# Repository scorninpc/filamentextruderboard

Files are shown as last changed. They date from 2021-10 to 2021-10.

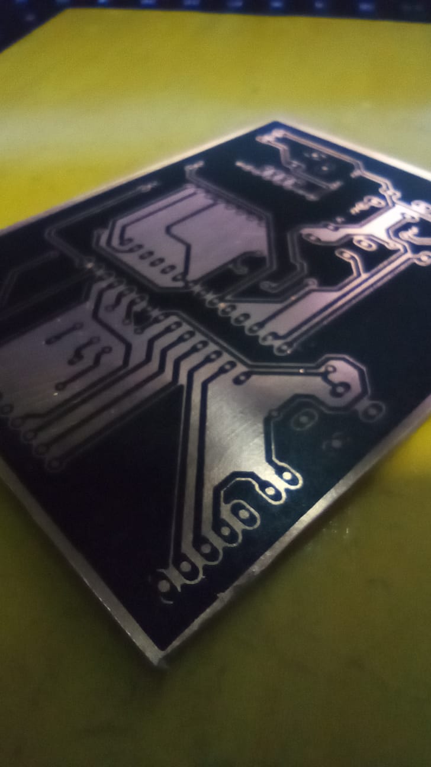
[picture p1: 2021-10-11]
board/photos/03.jpeg

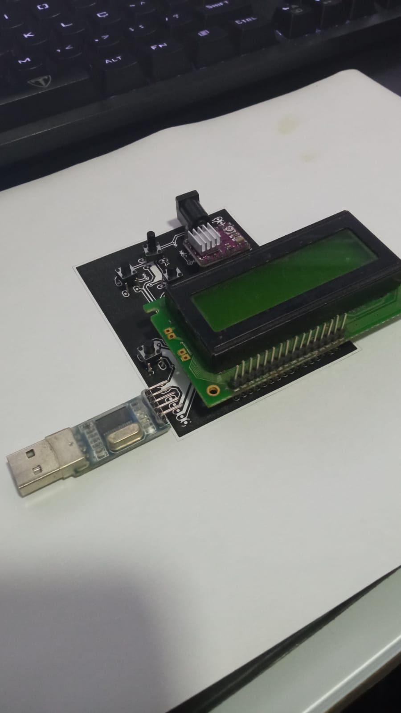
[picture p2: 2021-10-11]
board/photos/02.jpeg

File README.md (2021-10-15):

# Filament Extruder Board

Board to control heater and step motor for PET filament extruder

## Media

https://imgur.com/a/M2m6THj

## Tips

- Use MOSFET module to connect hotend. If you use 25A MOSFET module, this work only with 12v, so wire here (https://imgur.com/slLvls0) to use 5v of arduino

## How to use

- ENTER button to change what configure. Indicated by arrow
- UP and DOWN configure the value of indicated device
- LONG PRESS ENTER to start or stop the device indicated by arrow

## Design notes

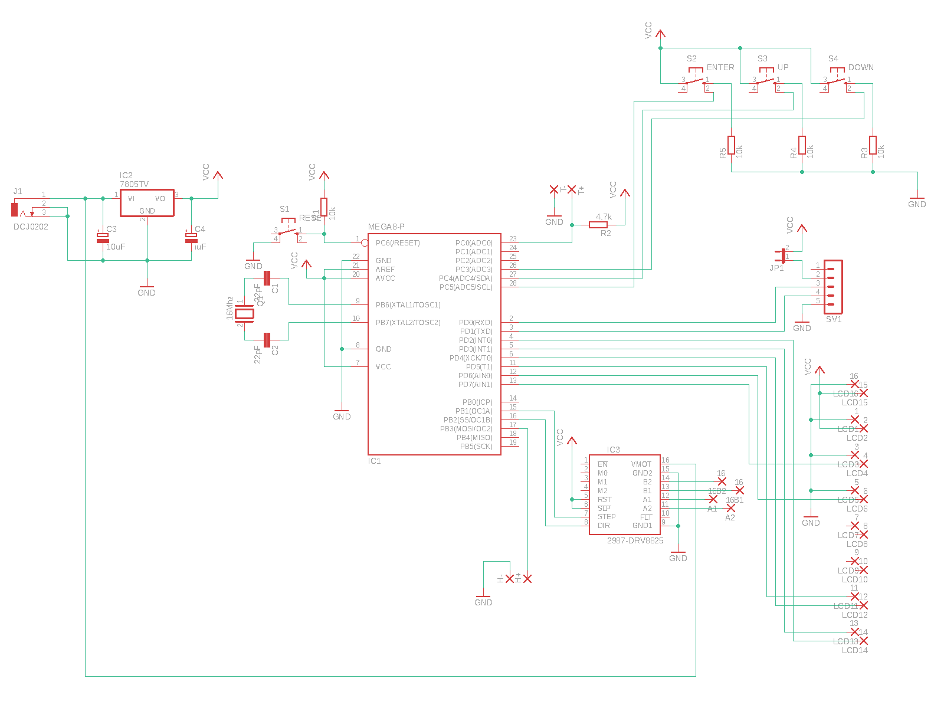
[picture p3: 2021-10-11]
board/schematic.png

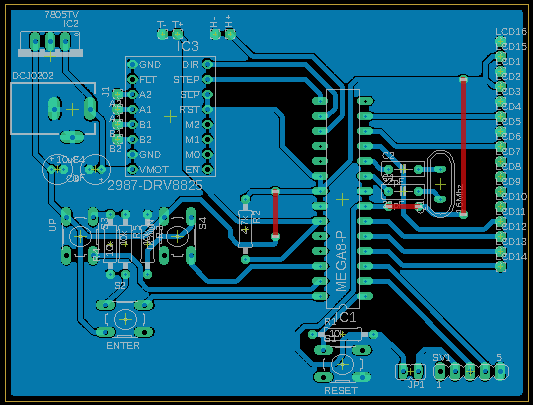
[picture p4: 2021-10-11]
board/board.png

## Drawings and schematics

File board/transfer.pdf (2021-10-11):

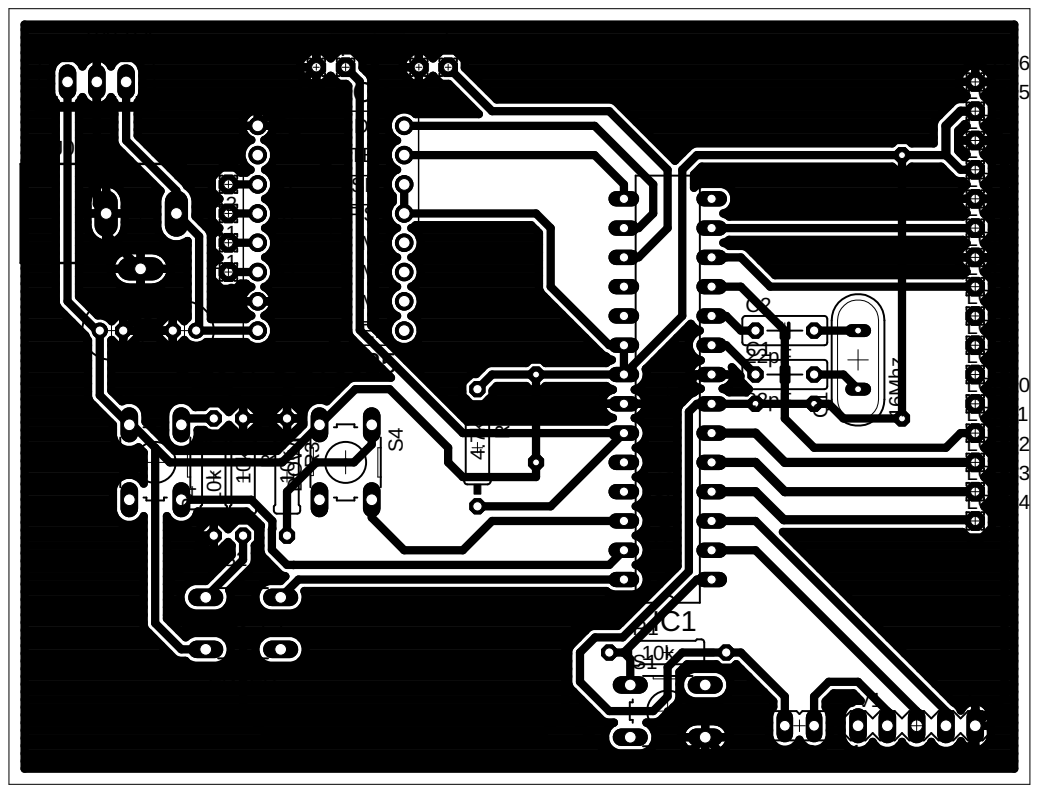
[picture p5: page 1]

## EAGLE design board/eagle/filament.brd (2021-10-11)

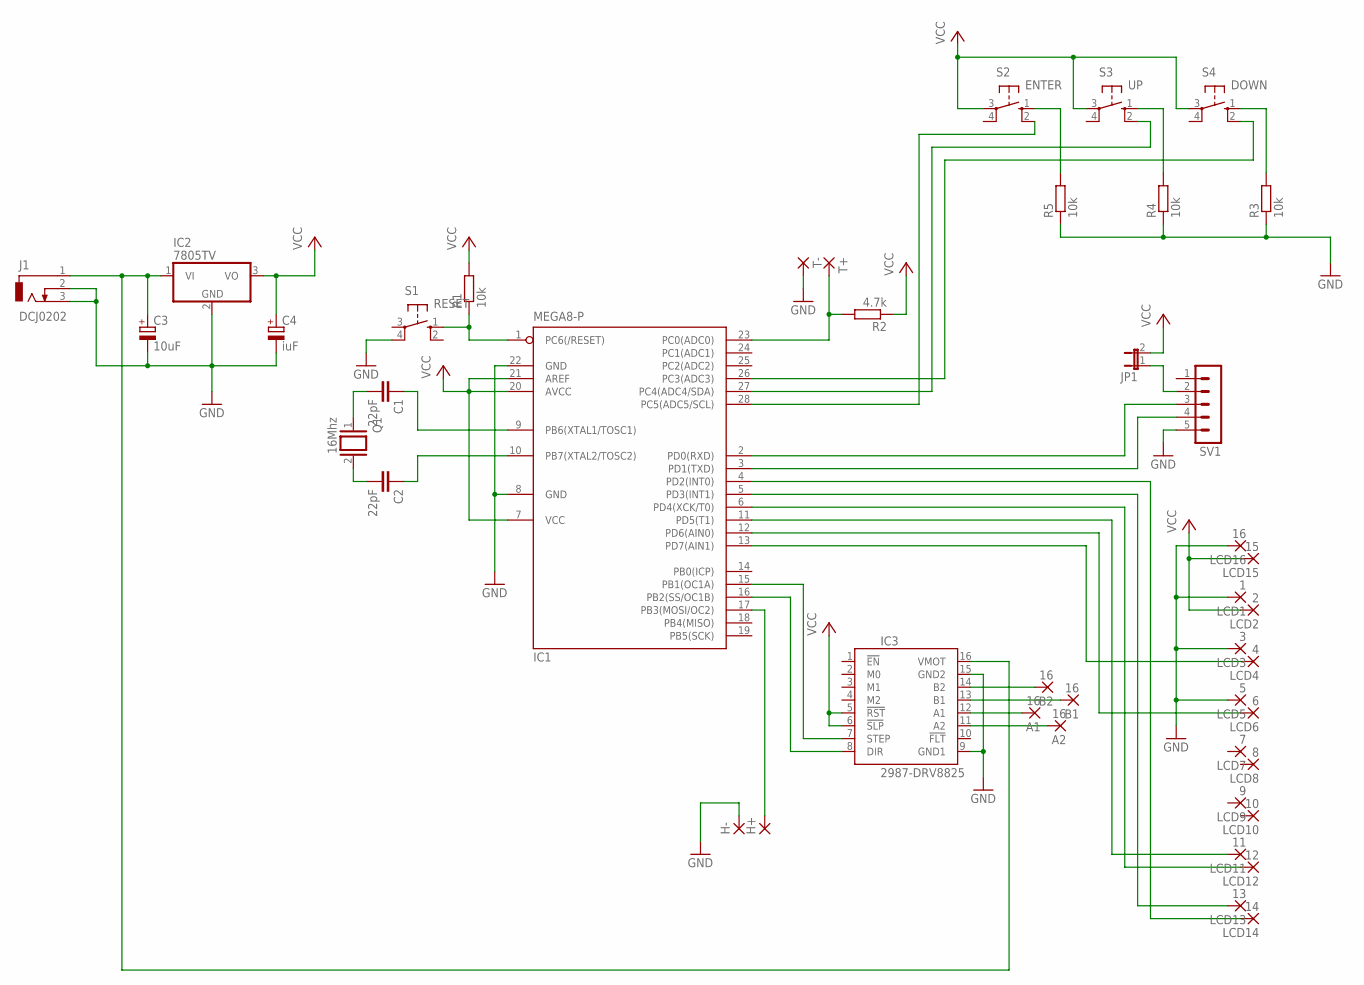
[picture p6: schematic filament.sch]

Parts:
A1, A2: 16; 1,6/0,8
B1, B2: 16; 1,6/0,8
C1, C2: 22pF; C050-025X075
C3: 10uF; E2-5
C4: iuF; E2-5
H+: 1,6/0,8
H-: 1,6/0,8
IC1: MEGA8-P; DIL28-3
IC2: 7805TV; TO220V
IC3: 2987-DRV8825; DRV8825
J1: DCJ0202
JP1: JP1E; JP1
LCD1: 1; 1,6/0,8
LCD2: 2; 1,6/0,8
LCD3: 3; 1,6/0,8
LCD4: 4; 1,6/0,8
LCD5: 5; 1,6/0,8
LCD6: 6; 1,6/0,8
LCD7: 7; 1,6/0,8
LCD8: 8; 1,6/0,8
LCD9: 9; 1,6/0,8
LCD10: 10; 1,6/0,8
LCD11: 11; 1,6/0,8
LCD12: 12; 1,6/0,8
LCD13: 13; 1,6/0,8
LCD14: 14; 1,6/0,8
LCD15: 15; 1,6/0,8
LCD16: 16; 1,6/0,8
Q1: 16Mhz; QS
R1, R3, R4, R5: 10k; 0207/10
R2: 4.7k; 0207/10
S1: RESET; B3F-10XX
S2: ENTER; B3F-10XX
S3: UP; B3F-10XX
S4: DOWN; B3F-10XX
SV1: MA05-1
T+: 1,6/0,8
T-: 1,6/0,8

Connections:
GND: C3.-, C4.-, H-.1, IC1.8 (GND), IC1.22 (GND), IC2.2 (GND), IC3.9 (GND1), IC3.15 (GND2), J1.2, J1.3, LCD1.1, LCD3.1, LCD5.1, LCD16.1, R3.1, R4.1, R5.1, S1.4 (P1), SV1.5, T-.1
unnamed: C1.2, Q1.1
unnamed: C2.2, Q1.2
unnamed: C2.1, IC1.10 (PB7(XTAL2/TOSC2))
unnamed: C1.1, IC1.9 (PB6(XTAL1/TOSC1))
unnamed: IC1.1 (PC6(/RESET)), R1.1, S1.1 (S)
unnamed: B2.1, IC3.14 (B2)
unnamed: IC1.3 (PD1(TXD)), SV1.4
unnamed: IC1.2 (PD0(RXD)), SV1.3
unnamed: JP1.1, SV1.2
unnamed: IC1.4 (PD2(INT0)), LCD14.1
unnamed: IC1.5 (PD3(INT1)), LCD13.1
unnamed: IC1.6 (PD4(XCK/T0)), LCD12.1
unnamed: IC1.11 (PD5(T1)), LCD11.1
unnamed: IC1.23 (PC0(ADC0)), R2.2, T+.1
unnamed: IC1.13 (PD7(AIN1)), LCD4.1
unnamed: H+.1, IC1.17 (PB3(MOSI/OC2))
unnamed: IC1.12 (PD6(AIN0)), LCD6.1
unnamed: R5.2, S2.1 (S)
unnamed: R4.2, S3.1 (S)
unnamed: R3.2, S4.1 (S)
unnamed: IC1.28 (PC5(ADC5/SCL)), S2.2 (S1)
unnamed: IC1.27 (PC4(ADC4/SDA)), S3.2 (S1)
unnamed: IC1.26 (PC3(ADC3)), S4.2 (S1)
unnamed: IC1.15 (PB1(OC1A)), IC3.7 (STEP)
unnamed: IC1.16 (PB2(SS/OC1B)), IC3.8 (DIR)
unnamed: B1.1, IC3.13 (B1)
unnamed: C3.+, IC2.1 (VI), IC3.16 (VMOT), J1.1
unnamed: A1.1, IC3.12 (A1)
unnamed: A2.1, IC3.11 (A2)
VCC: C4.+, IC1.7 (VCC), IC1.20 (AVCC), IC1.21 (AREF), IC2.3 (VO), IC3.5 (!RST), IC3.6 (!SLP), JP1.2, LCD2.1, LCD15.1, R1.2, R2.1, S2.3, S3.3, S4.3

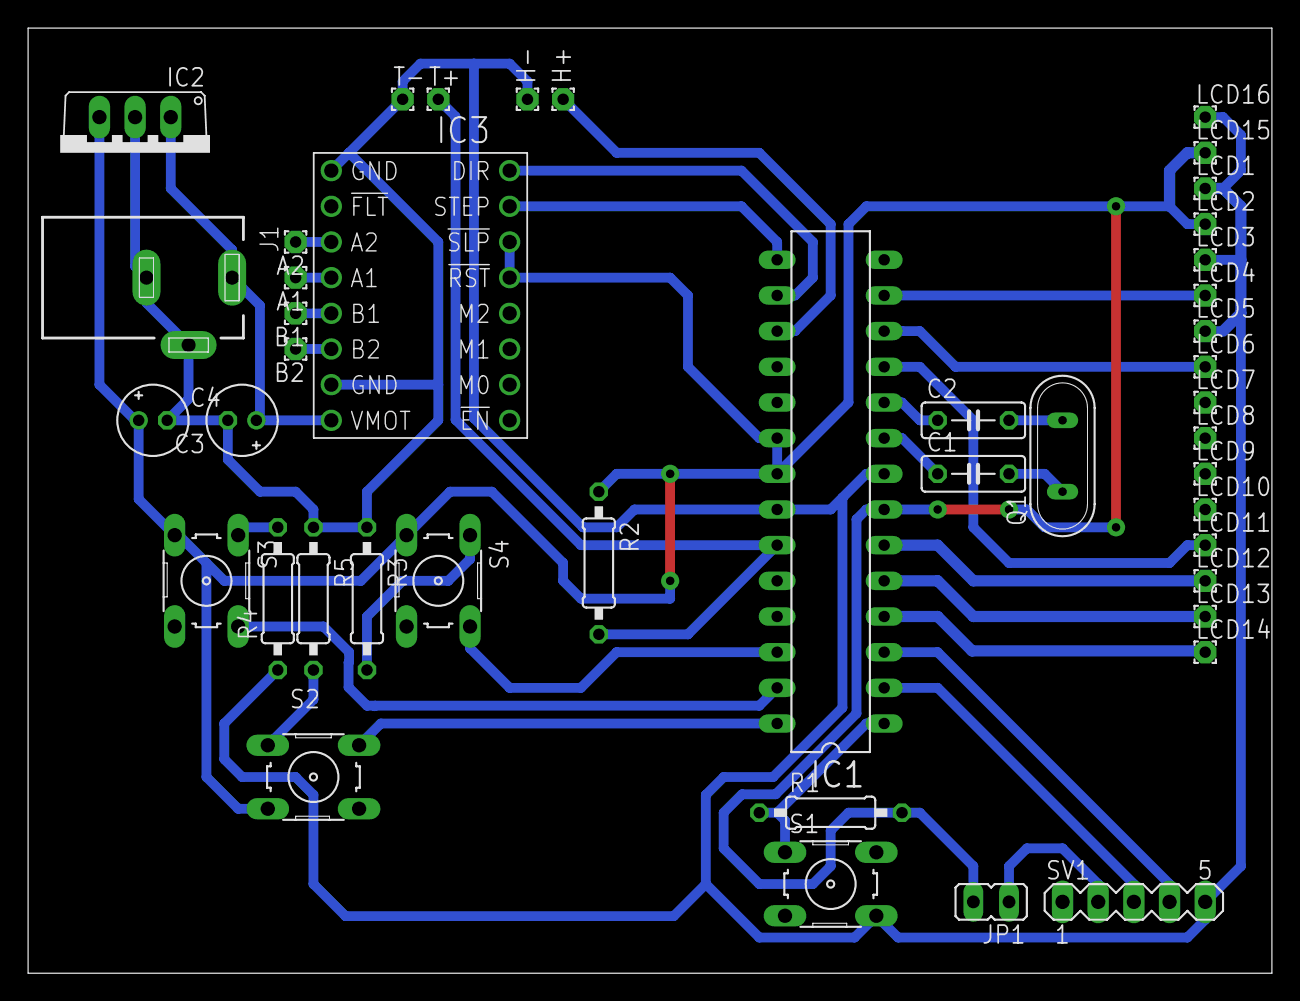
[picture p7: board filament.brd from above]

Board: 2 copper layers, 88.6 x 67.3 mm, 44 parts (0 on the bottom side), 31 nets.

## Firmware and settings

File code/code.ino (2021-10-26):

/**
 * arduino-cli compile --fqbn arduino:avr:uno code
 * arduino-cli upload -p /dev/ttyUSB0  --fqbn arduino:avr:uno code
 */

#include <LiquidCrystal.h>
#include <PID.h>
#include <EEPROM.h>
#include "Button.h"
#include <AccelStepper.h>


// Define PINS
#define THERMISTOR_PIN A0

#define LCD_RS_PIN 7
#define LCD_EN_PIN 6
#define LCD_D4_PIN 5
#define LCD_D5_PIN 4
#define LCD_D6_PIN 3
#define LCD_D7_PIN 2

#define HEATER_PIN 11

#define BTN_PLUS A4
#define BTN_MINUS A3
#define BTN_ENTER A5

// Config to store on eeprom
struct MyConfig {
	int temperature;
	unsigned long motor;
	unsigned long saved;
};
struct MyConfig eepromConfig = (MyConfig){ 35, 0, 0};

// Thermistor
int temperatureDesired = 35;
int temperatureCurrent = 0;
int heaterValue = 0;
bool heaterOn = false;

arc::PID<double> temperaturePid(1.0, 0.05, 0.25);

// LCD
LiquidCrystal lcd(LCD_RS_PIN, LCD_EN_PIN, LCD_D4_PIN, LCD_D5_PIN, LCD_D6_PIN, LCD_D7_PIN);
unsigned long lcd_last_refresh = 0;

byte customArrow[] = {
	0x00,
	0x08,
	0x0C,
	0x0E,
	0x0E,
	0x0C,
	0x08,
	0x00
};

byte customGraus[] = {
	0x00,
	0x06,
	0x09,
	0x09,
	0x06,
	0x00,
	0x00,
	0x00
};

byte customOff[] = {
	0x04,
	0x0A,
	0x0A,
	0x0A,
	0x0A,
	0x11,
	0x1F,
	0x0E
};

byte customOn[] = {
	0x04,
	0x0E,
	0x0E,
	0x0E,
	0x0E,
	0x1F,
	0x1F,
	0x0E
};

byte customMotorOff[] = {
	0x00,
	0x00,
	0x04,
	0x1F,
	0x11,
	0x11,
	0x1F,
	0x00
};

byte customMotorOn[] = {
	0x00,
	0x00,
	0x04,
	0x1F,
	0x1D,
	0x17,
	0x1F,
	0x00
};

// Button
Button btn_enter(BTN_ENTER, 1000);
Button btn_minus(BTN_MINUS);
Button btn_plus(BTN_PLUS);

int buttonIndicatorLocation = 0;

// Motor
byte directionPin = 10;
byte stepPin = 9;
int numberOfSteps = 100;
unsigned long step_last_pulse = 0;
unsigned long step_speed_pulse = 0;
bool motorOn = false;

int motorSpeed = 1000;
AccelStepper stepper = AccelStepper(1, stepPin, directionPin);

/**
 * Refresh LCD screen
 */
void refreshLCD()
{
	lcd.clear();

	// Set indicator
	lcd.setCursor(0, buttonIndicatorLocation);
	lcd.write(byte(0));

	// Line 1
	lcd.setCursor(1, 0);
	lcd.print(" ");
	if(heaterOn) {
		lcd.write(byte(2));
	}
	else {
		lcd.write(byte(3));
	}

	lcd.print(" ");
	lcd.print(temperatureCurrent);

	lcd.print("/");
	lcd.print(temperatureDesired);
	lcd.write(byte(1));

	// Line 2
	lcd.setCursor(1, 1);
	lcd.print(" ");
	if(motorOn) {
		lcd.write(byte(5));
	}
	else {
		lcd.write(byte(4));
	}
	lcd.print(" ");
	// lcd.print(step_speed_pulse);
	lcd.print(motorSpeed);
	

	// Store time as last refresh
	lcd_last_refresh = millis();
}


/**
 * Control temperature PID
 */

unsigned char ledValue = 0;
void temperaturePID()
{
	// Control PID
	temperaturePid.setTarget(temperatureDesired);
	temperaturePid.setInput(temperatureCurrent);
	heaterValue = min(255,max(0,heaterValue + temperaturePid.getOutput()));
	
	// Verify if heater is on
	if(!heaterOn) {
		analogWrite(HEATER_PIN, 0);
		return;
	}
	else {
		analogWrite(HEATER_PIN, heaterValue);
	}
}

/**
 * Setup
 */
void setup()
{
	

	// Heater
	pinMode(HEATER_PIN, OUTPUT);
	digitalWrite(HEATER_PIN, LOW);

	// Start LCD and custom chars
	lcd.begin(16, 2);
	lcd.createChar(0, customArrow);
	lcd.createChar(1, customGraus);
	lcd.createChar(2, customOn);
	lcd.createChar(3, customOff);
	lcd.createChar(4, customMotorOff);
	lcd.createChar(5, customMotorOn);
	lcd.clear();

	//
	EEPROM.get(0x0, eepromConfig);
	if(eepromConfig.saved == 1) {
		motorSpeed = eepromConfig.motor;
		temperatureDesired = eepromConfig.temperature;
	}


	// Step motor
	stepper.setMaxSpeed(1500);
}


#define NUMTEMPS 20
short temptable[NUMTEMPS][2] = {
   {1, 841},
   {54, 255},
   {107, 209},
   {160, 184},
   {213, 166},
   {266, 153},
   {319, 142},
   {372, 132},
   {425, 124},
   {478, 116},
   {531, 108},
   {584, 101},
   {637, 93},
   {690, 86},
   {743, 78},
   {796, 70},
   {849, 61},
   {902, 50},
   {955, 34},
   {1008, 3}
};
int rawtemp = 0;
int current_celsius = 0;
byte i = 0;
byte temperature_times = 0;
unsigned long temperature_last_fetch = 0;



#define SERIESRESISTOR 4700   

/**
 * Loop
 */
void loop()
{
	// Store current temperature and Control temp PID
	rawtemp = rawtemp + analogRead(THERMISTOR_PIN);
	temperature_times++;
	// if((millis() - temperature_last_fetch) > 50) {
	if(temperature_times >= 5) {

		temperature_times = 0;
		rawtemp = rawtemp / 5;

		i++;
		if(i<NUMTEMPS) {
			rawtemp = analogRead(THERMISTOR_PIN);
			if (temptable[i][0] > rawtemp) {
				temperatureCurrent  = (int)temptable[i-1][1] + (rawtemp - temptable[i-1][0]) * (temptable[i][1] - temptable[i-1][1]) / (temptable[i][0] - temptable[i-1][0]);
				i=0;
				rawtemp = 0;
			}
		}
		else {
			i=0;
		}

		// Store time as last refresh
		// temperature_last_fetch = millis();
	}
	temperaturePID();


	// Pulse motor
	if(motorOn) {
		stepper.runSpeed();
	}

	// Handle button ENTER
	short btn1 = btn_enter.checkPress();
	if (btn1 == 1) {
		if(buttonIndicatorLocation == 1) {
			buttonIndicatorLocation = 0;
		}
		else if(buttonIndicatorLocation == 0) {
			buttonIndicatorLocation = 1;
		}
	} 
	else if (btn1 == -1) {
		if(buttonIndicatorLocation == 1) {
			motorOn = !motorOn;
			stepper.setSpeed(motorSpeed);
		}
		else if(buttonIndicatorLocation == 0) {
			heaterOn = !heaterOn;
			stepper.setSpeed(motorSpeed);
		}
		
		eepromConfig.motor = motorSpeed;
		eepromConfig.temperature = temperatureDesired;
		eepromConfig.saved = 1;

		EEPROM.put(0x0, eepromConfig);
	}

	// Handle button UP
	short btn2 = btn_plus.checkPress();
	if (btn2 == 1) {
		if(buttonIndicatorLocation == 0) {// Temperature
			temperatureDesired++;
		}
		else if(buttonIndicatorLocation == 1) {// Motor
			motorSpeed+=50;
			stepper.setSpeed(motorSpeed);
		}
	} 

	// Handle button DOWN
	short btn3 = btn_minus.checkPress();
	if (btn3 == 1) {
		if(buttonIndicatorLocation == 0) {// Temperature
			temperatureDesired--;
		}
		else if(buttonIndicatorLocation == 1) { // Motor
			motorSpeed-=50;
			if(motorSpeed < 0) {
				motorSpeed = 0;
			}

			stepper.setSpeed(motorSpeed);
		}
	}

	// Refresh screen
	if((millis() - lcd_last_refresh) > 100) {
		refreshLCD();
	}
}

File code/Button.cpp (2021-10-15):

/**
 * https://github.com/davidepalladino/Button-Arduino
 */

#include "Button.h"

Button::Button(uint8_t pin) : Button(pin, B_NOPULLUP, DEFAULT_LONG_PRESS) {}

Button::Button(uint8_t pin, input_t mode) : Button(pin, mode, DEFAULT_LONG_PRESS) {}

Button::Button(uint8_t pin, uint32_t timeLongPress) : Button(pin, B_NOPULLUP, timeLongPress) {}

Button::Button(uint8_t pin, input_t mode, uint32_t timeLongPress) {
    this->pin = pin;

    setMode(mode);
    setValuePress();

    pinMode(this->pin, this->mode);
    
    setTimeLongPress(timeLongPress);
}

void Button::setTimeLongPress(uint32_t timeLongPress) { this->timeLongPress = timeLongPress; }

uint32_t Button::getTimeLongPress() { return timeLongPress; }

int8_t Button::checkPress() {  
    /* Read and save the value for next analysis. */
    uint8_t valueRead = digitalRead(pin);

    /* Cheching if the button is pressed in this moment. */
    if (valueRead == valuePress) {
        /* Checking if is the first press or not. */
        if (!isPressed) {
            //Serial.println("Is pressed.");
            isPressed = true;

            /* Checking if is set the time of long press. If there is a value, will be set the timeout. */
            if (getTimeLongPress() > DEFAULT_LONG_PRESS) {
                timeOut = millis() + getTimeLongPress();
            }

        } else {
            /* Checking if is the long press. */
            if ((millis() >= timeOut) && (getTimeLongPress() > DEFAULT_LONG_PRESS) && !isLongPressed) {
                //Serial.println("Is long press on first time.");
                actualValue = -1;
                isLongPressed = true;
            } else if (isLongPressed) {
                actualValue = 0;
            } else {
                actualValue = 0;
            }
        }
    
    /* Else, the button is not pressed in this moment. */
    } else {
        /* Checking if is the short press, verifying if is set the "timeLongPress" or not. */      
        if (isPressed && (((actualValue != -1) && (millis() < timeOut) && !isLongPressed) || (getTimeLongPress() == DEFAULT_LONG_PRESS))) {
            //Serial.println("Is short press.");
            isPressed = false;
            isLongPressed = false;
            
            actualValue = 1;

        /* Else, is not a press. */
        } else {
            //Serial.println("Is not pressed.");
            isPressed = false;
            isLongPressed = false;
            
            actualValue = 0;
        }
    }
    
    return actualValue;
}

void Button::setMode(input_t mode) {
    /* Translation of "mode" parameter "B_NOPULLUP"/"B_PULLUP" to the rispective "INPUT"/"INPUT_PULLUP". */
    if (mode == B_NOPULLUP) {
        this->mode = INPUT;
    } else if (mode == B_PULLUP) {
        this->mode = INPUT_PULLUP;
    }
}

void Button::setValuePress() {
    /* Checking what is the value of press, "HIGH" if the mode is INPUT; "LOW" if is INPUT_PULLUP. */
    if (mode == INPUT) {
        valuePress = HIGH;
    } else if (mode == INPUT_PULLUP) {
        valuePress = LOW;
    }
}

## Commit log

2021-10-15 Added long press of 3s on temp to on/off the heater Added * to show if heater is on or off Correction of target value if its less than 100
    [Button.cpp, Button.h, code.ino]
2021-10-15 added PID control to heater
2021-10-15 added long press to on/off motor and heater added icon to indicate if motor and heater is on or off added initial info of motor on screen added last config (motor speed and destiny temperature) to EE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
2021-10-15 fix start and stop motor
    [code.ino]
2021-10-24 Added heater to PWM pin Added step driver for 1/8 microsteps for less noise Removed lib to get temperature, so now we added a non-blocking read temperature for 3950 Added accelstepper for motor step 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
    [code.ino]
2021-10-24 Fixed unnecessary thermistor lib fix PID to run without heather enabled (need to rewrite this PID method, its not good for high temps)
    [code.ino]
2021-10-26 Removed the time for calc temperature. now the loop get the 5 lasts read, and calculate the temperature. PID must be real time
